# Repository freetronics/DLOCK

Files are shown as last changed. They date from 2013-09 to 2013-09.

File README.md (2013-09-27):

Freetronics RFID Door Lock Shield
==================================
Copyright 2013 Freetronics Pty Ltd  
Freetronics site:  www.freetronics.com  
Freetronics email: info@freetronics.com  

Based on the circuit described in the "RFID Access Control" project in
the book "Practical Arduino", this shield allows you to control a door
lock using an electric strike plate using a number of commonly
available RFID reader modules.

Supported reader modules include:

 * ID12
 * ID20
 * RDM630
 * RDM880
 * HF MultiTag

Features:

 * Reset button wired through to Arduino reset pin.
 * Blue "Arduino power on" LED with current-limiting resistor.
 * 100nF bypass/smoothing capacitor on supply rails.
 * Overlay guide where you need it: both top and bottom.

Compatible with the Freetronics TwentyTen, Arduino Uno, Arduino
Duemilanove, and other compatible boards based on the same header
format.

More information is available at:

  http://www.freetronics.com/dlock
  http://www.practicalarduino.com/projects/rfid-access-control

INSTALLATION
------------
The design is saved as an EAGLE project. EAGLE PCB design software is
available from www.cadsoftusa.com free for non-commercial use. To use
this project download it and place the directory containing these files
into the "eagle" directory on your computer. Then open EAGLE and
navigate to Projects -> eagle -> DLOCK.

DISTRIBUTION
------------
The specific terms of distribution of this project are governed by the
license referenced below.

LICENSE
-------
Licensed under the TAPR Open Hardware License (www.tapr.org/OHL).
The "license" folder within this repository also contains a copy of
this license in plain text format.

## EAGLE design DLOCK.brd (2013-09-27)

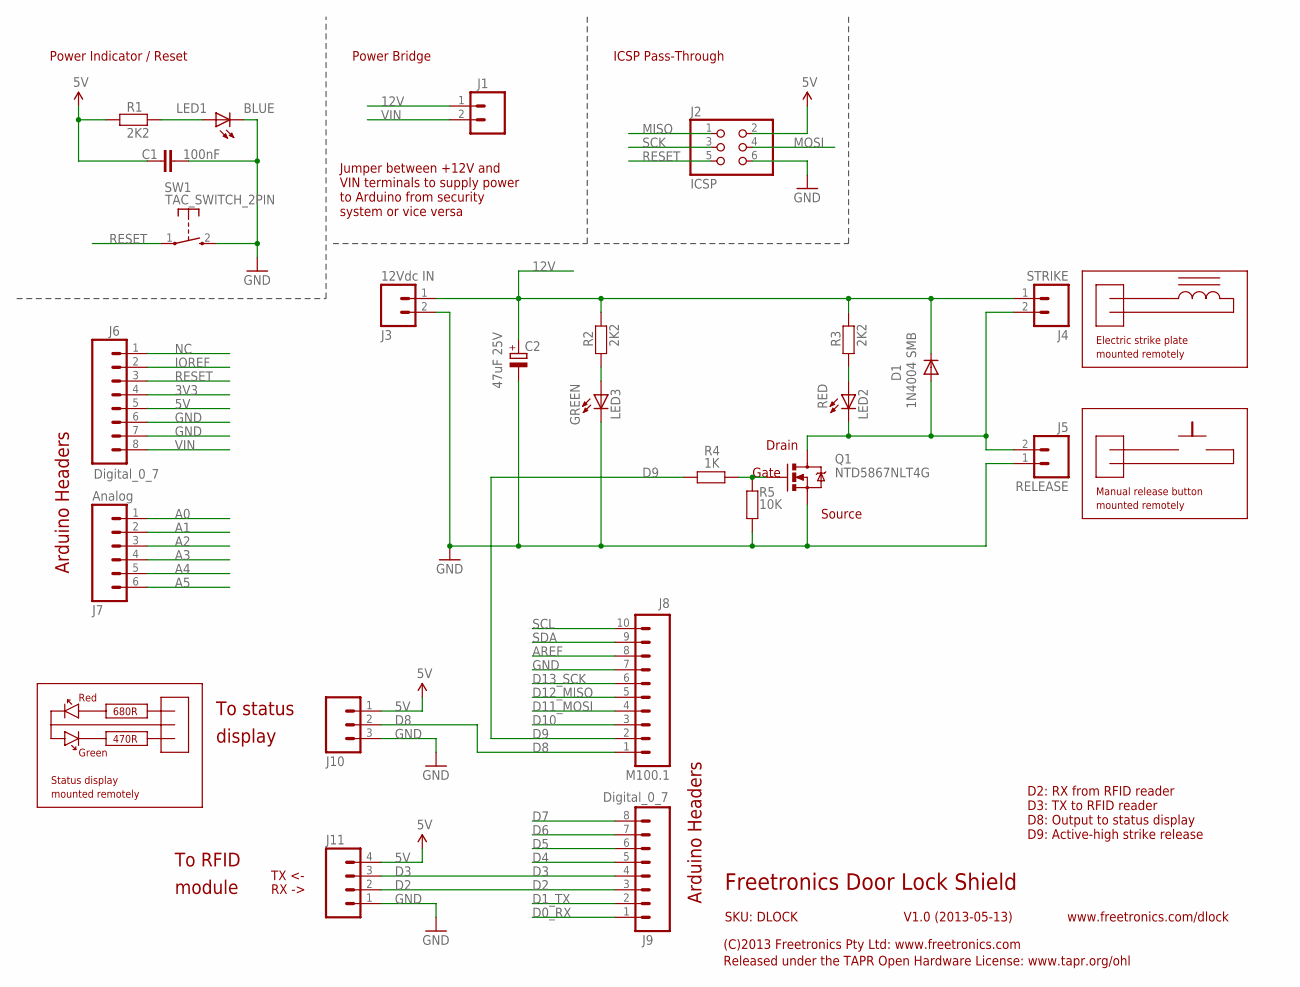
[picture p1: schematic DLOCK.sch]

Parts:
C1: 100nF; 0603
C2: 47uF 25V; PANASONIC_D
D1: 1N4004 SMB; SMB-DIODE
J1: M02PTH; 1X02
J2: ICSP; 2X03
J3: 12Vdc IN; SCREWTERMINAL-3.5MM-2
J4: STRIKE; SCREWTERMINAL-3.5MM-2
J5: RELEASE; 1X02
J6, J9: Digital_0_7; 1X08
J7: Analog; 1X06
J8: M100.1; 1X10
J10: M03PTH; 1X03
J11: M04PTH; 1X04
LED1: BLUE; LED-0603
LED2: RED; LED-0603
LED3: GREEN; LED-0603
Q1: NTD5867NLT4G; DPACK
R1, R2, R3: 2K2; 0603
R4: 1K; 0603
R5: 10K; 0603
SW1: TAC_SWITCH_2PIN; TACTILE_SWITCH_SMD_2PIN_TINY

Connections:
3V3: J6.4
5V: C1.1, J2.2, J6.5, J10.1, J11.4, R1.1
12V: C2.+, D1.C, J1.1, J3.1, J4.1, R2.2, R3.2
A0: J7.1
A1: J7.2
A2: J7.3
A3: J7.4
A4: J7.5
A5: J7.6
AREF: J8.8
D0_RX: J9.1
D1_TX: J9.2
D2: J9.3, J11.2
D3: J9.4, J11.3
D4: J9.5
D5: J9.6
D6: J9.7
D7: J9.8
D8: J8.1, J10.2
D9: J8.2, R4.2
D10: J8.3
D11_MOSI: J8.4
D12_MISO: J8.5
D13_SCK: J8.6
GND: C1.2, C2.-, J2.6, J3.2, J5.1, J6.6, J6.7, J8.7, J10.3, J11.1, LED1.C, LED3.C, Q1.3 (S), R5.1, SW1.2 (S)
IOREF: J6.2
MISO: J2.1
MOSI: J2.4
unnamed: D1.A, J4.2, J5.2, LED2.C, Q1.2 (D)
unnamed: LED2.A, R3.1
unnamed: Q1.1 (G), R4.1, R5.2
unnamed: LED3.A, R2.1
unnamed: LED1.A, R1.2
NC: J6.1
RESET: J2.5, J6.3, SW1.1
SCK: J2.3
SCL: J8.10
SDA: J8.9
VIN: J1.2, J6.8

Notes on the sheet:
Arduino Headers
To RFID
module
TX <-
RX ->
To status
display
680R
470R
Red
Green
Status display
mounted remotely
Manual release button
Electric strike plate
D2: RX from RFID reader D3: TX to RFID reader D8: Output to status display D9: Active-high strike release
Drain
Gate
Source
Freetronics Door Lock Shield
V1.0 (2013-05-13)
SKU: DLOCK
(C)2013 Freetronics Pty Ltd: www.freetronics.com
Released under the TAPR Open Hardware License: www.tapr.org/ohl
www.freetronics.com/dlock
Power Indicator / Reset
Power Bridge
Jumper between +12V and VIN terminals to supply power to Arduino from security system or vice versa
ICSP Pass-Through

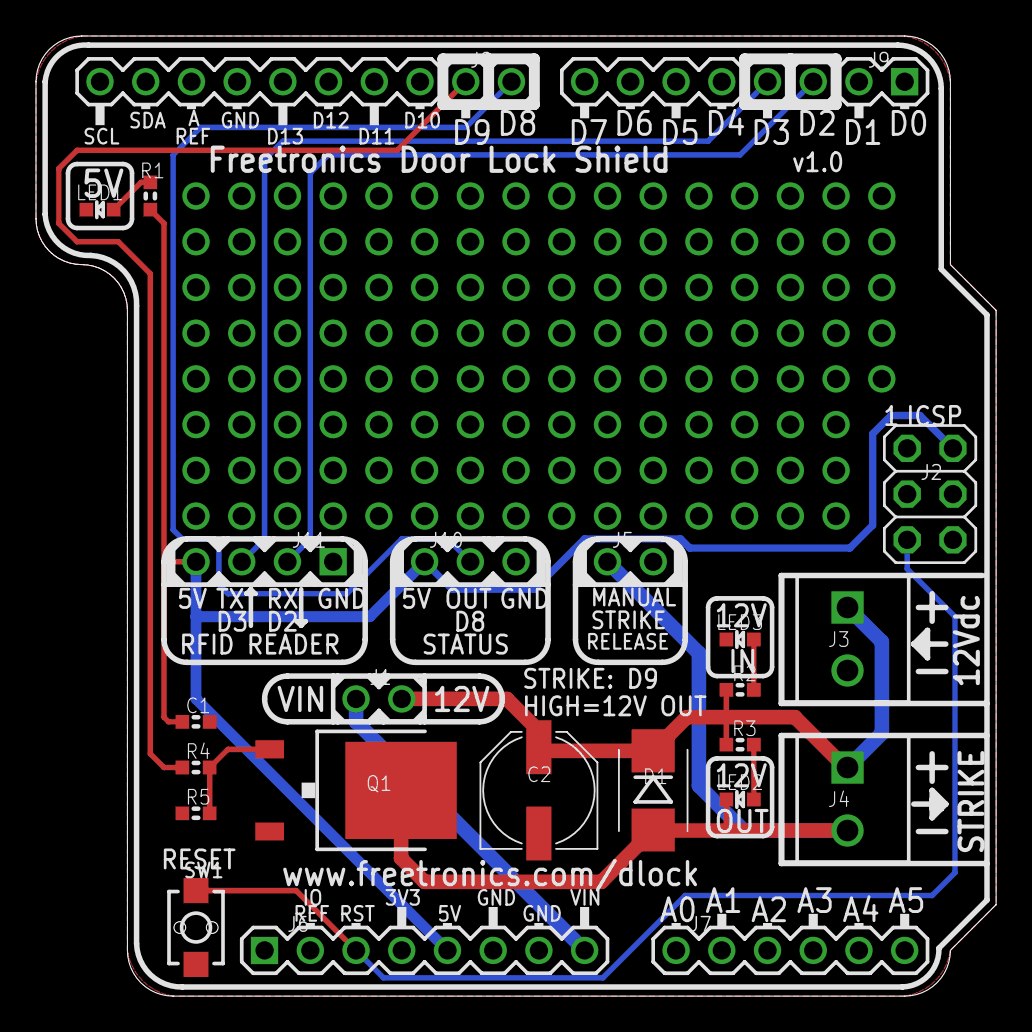
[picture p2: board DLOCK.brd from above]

Board: 2 copper layers, 53.3 x 53.3 mm, 24 parts (0 on the bottom side), 14 nets.
